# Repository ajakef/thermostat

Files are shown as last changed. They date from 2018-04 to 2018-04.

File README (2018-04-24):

The thermostat pcb is a bit more general than the name suggests: basically, it's a shield for turning any device on and off depending on the reading of one or two sensors, according to rules programmed in Arduino code.

It requires 120/240 V AC power and a load current of less than 10 A. The max load current can be increased to 15 A by swapping in a slightly more expensive relay. A built-in AC-DC converter (again, 120/240 V) powers the Arduino and shield with up to 1 W (more than enough for most Arduino applications).

The user is responsible for cutting a power cord and connecting it to the correct screw terminals; color-coding and text labels make this safe and straightforward.

The shield is intended to work with thermistors connected to screw terminals. However, any passive analog sensor compatible with the Arduino's ADC can also be connected to the screw terminal, and a powered analog sensor can also be used by soldering the 5V lead to the board.

Schematic symbols are all stored in thermostat.lib. Component footprints are all stored in thermostat.pretty/. There should be no library issues.

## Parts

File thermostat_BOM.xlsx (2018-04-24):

Quantity | Description | Specs | Price per unit | Total cost | Link | Comments
1 | Relay | 5V/40mA coil, 277VAC/10A switch | $1.45 | $1.45 | https://www.digikey.com/product-detail/en/omron-electronics-inc-emc-div/G5Q-1A4-EU-DC5/Z4268-ND/2755285
0 | Relay | 5V/40mA coil, 250VAC/15A switch | 4.09 | $0.00 | https://www.digikey.com/product-detail/en/omron-electronics-inc-emc-div/G5CA-1A-E-DC5/Z2161-ND/699988 | only needed for currents above 10 A
1 | NPN Transistor |  | 0.24 | $0.24 | https://www.digikey.com/product-detail/en/on-semiconductor/KSP2222ATA/KSP2222ATACT-ND/3025280
1 | Thermistor | 100k | 3.36 | $3.36 | https://www.digikey.com/product-detail/en/cantherm/CWF1B104H3950/317-1315-ND/1191090
1 | Resistor | 100k, 0.1% | 0.46 | $0.46 | https://www.digikey.com/product-detail/en/yageo/MFP-25BRD52-100K/100KADCT-ND/2059112
1 | Resistor | 1k, 5% | 0.1 | $0.10 | https://www.digikey.com/product-detail/en/stackpole-electronics-inc/CF14JT1K00/CF14JT1K00CT-ND/1830350
1 | set of headers |  | 0.66 | $0.66 | https://www.digikey.com/product-detail/en/sullins-connector-solutions/PRPC040SAAN-RC/S1011EC-40-ND/2775214
1 | Screw Terminal | Gray, 0.2-inch, 2-pin | 0.93 | $0.93 | https://www.digikey.com/product-detail/en/te-connectivity-amp-connectors/1546217-2/A112360-ND/1827544
1 | Screw Terminal | Black, 0.2-inch, 2-pin | 0.9 | $0.90 | https://www.digikey.com/product-detail/en/molex-llc/0398800302/WM4393-ND/2421325
1 | Screw Terminal | Blue, 0.2-inch, 2-pin | 0.73 | $0.73 | https://www.digikey.com/product-detail/en/on-shore-technology-inc/OSTTA024163/ED2580-ND/614529
1 | Printed Circuit Board |  | 7 | $7.00 | http://oshpark.com
 |  | Total Required Components Cost: |  | $15.83
Optional Components
1 | potentiometer | 10k | 3.65 | $3.65 | https://www.digikey.com/product-detail/en/bourns-inc/3310Y-025-103L/3310Y-025-103L-ND/2534071
1 | Buzzer | 5V, 2.4 kHz, 50 mA→85dB | 1.09 | $1.09 | https://www.digikey.com/products/en/audio-products/alarms-buzzers-and-sirens/157?k=ccg-120
1 | LCD | 2x16, transmissive LCD, includes pot and header | 9.95 | $9.95 | https://www.digikey.com/product-detail/en/adafruit-industries-llc/181/1528-1502-ND/5774228
1 | SD card slot |  | 7.5 | $7.50 | https://www.adafruit.com/product/254
1 | AC-DC converter | 100-240 VAC to 5 VDC | 6.34 | $6.34 | https://www.digikey.com/product-detail/en/recom-power/RAC01-05SGA/945-3043-ND/6677085
1 | Thermistor | 100k | 3.36 | $3.36 | https://www.digikey.com/product-detail/en/cantherm/CWF1B104H3950/317-1315-ND/1191090 | for an optional second sensor
1 | Resistor | 100k, 0.1% | 0.46 | $0.46 | https://www.digikey.com/product-detail/en/yageo/MFP-25BRD52-100K/100KADCT-ND/2059112 | for an optional second sensor
 |  | Total Optional Components Cost: |  | $32.35

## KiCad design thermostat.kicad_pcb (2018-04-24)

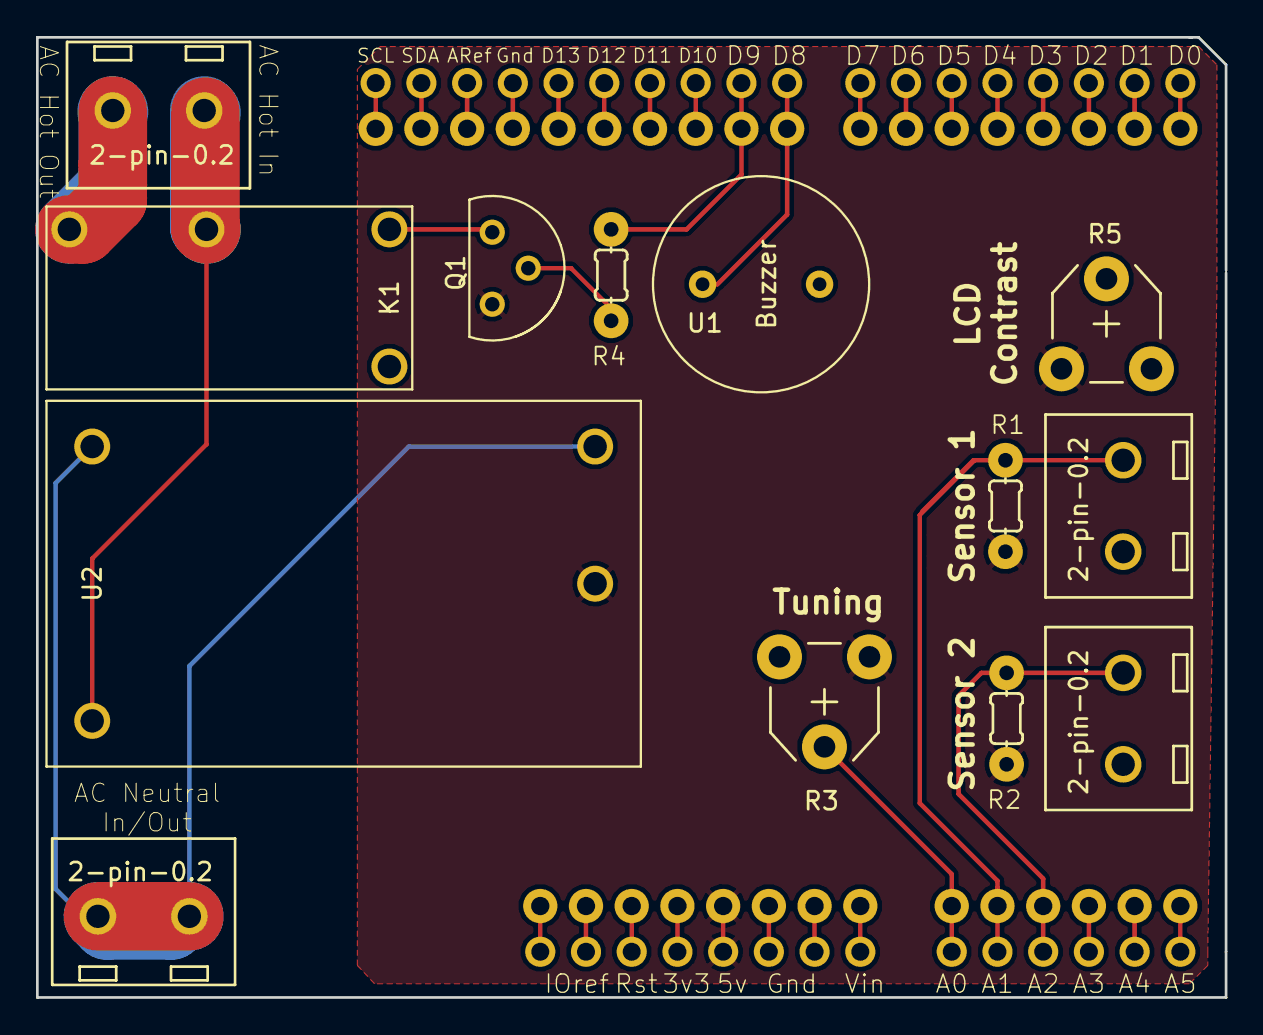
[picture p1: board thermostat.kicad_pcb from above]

Board: 2 copper layers, 66.0 x 53.3 mm, 46 parts (0 on the bottom side), 34 nets.

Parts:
K1: RELAY_SPST; Relay-SPST-0.3-0.4
M1: ARDUINOUNOR3-JFA; ARDUINOR3-JFA
PAD1, PAD2, PAD3, PAD4, PAD5, PAD6, PAD7, PAD8, PAD9, PAD10, PAD11, PAD12, PAD13, PAD14, PAD15, PAD16, PAD17, PAD18, PAD19, PAD20, PAD21, PAD22, PAD23, PAD24, PAD25, PAD26, PAD27, PAD28, PAD29, PAD30, PAD31, PAD32: WIREPAD2_15_1_0; 2_15_1_0
Q1: PN2222A; transistor
R1, R2: 100k; R_0.2
R3, R5: POT; Potentiometer_VishaySpectrol-Econtrim-Type36T
R4: 1k; R_0.2
U1: Buzzer; Buzzer-6.5mm
U2: AC-DC-Converter; AC-DC-RAC01-GA
U3, U4, U5, U6: 2-pin-0.2

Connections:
120VAC: K1.2, U2.1, U5.1
+5V: M1.5V, PAD15.1, Q1.3, R1.2, R2.1, R3.1, R5.1, U2.4
Earth: K1.5, M1.GND, M1.GND1, M1.GND2, PAD4.1, PAD16.1, PAD18.1, R3.3, R5.3, U1.2, U2.2, U2.3, U3.1, U4.1, U6.1, U6.2
unnamed: K1.1, Q1.1
unnamed: K1.3, U5.2
unnamed: M1.3V, PAD13.1
unnamed: M1.A0, PAD23.1, R3.2
unnamed: M1.A1, PAD25.1, R1.1, U3.2
unnamed: M1.A2, PAD27.1, R2.2, U4.2
unnamed: M1.A3, PAD29.1
unnamed: M1.A4, PAD31.1
unnamed: M1.A5, PAD32.1
unnamed: M1.AREF, PAD3.1
unnamed: M1.D0, PAD30.1
unnamed: M1.D1, PAD28.1
unnamed: M1.D2, PAD26.1
unnamed: M1.D3, PAD24.1
unnamed: M1.D4, PAD22.1
unnamed: M1.D5, PAD21.1
unnamed: M1.D6, PAD19.1
unnamed: M1.D7, PAD17.1
unnamed: M1.D8, PAD14.1, U1.1
unnamed: M1.D9, PAD12.1, R4.2
unnamed: M1.D10, PAD10.1
unnamed: M1.D11, PAD8.1
unnamed: M1.D12, PAD6.1
unnamed: M1.D13, PAD5.1
unnamed: M1.IORE, PAD9.1
unnamed: M1.NC, PAD7.1
unnamed: M1.RESE, PAD11.1
unnamed: M1.SCL, PAD1.1
unnamed: M1.SDA, PAD2.1
unnamed: M1.VIN, PAD20.1
unnamed: Q1.2, R4.1
